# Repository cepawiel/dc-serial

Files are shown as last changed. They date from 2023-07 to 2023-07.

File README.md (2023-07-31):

# Dreamcast Serial Adapters

## [CP2102N Adapter](DCSDv2_CP2102N/README.md)
Replacement PCB for the Dreamcast SD to Serial adapters
that are available online. Intended to be used with [dcload-serial](https://github.com/KallistiOS/dcload-serial/) for development of homebrew.
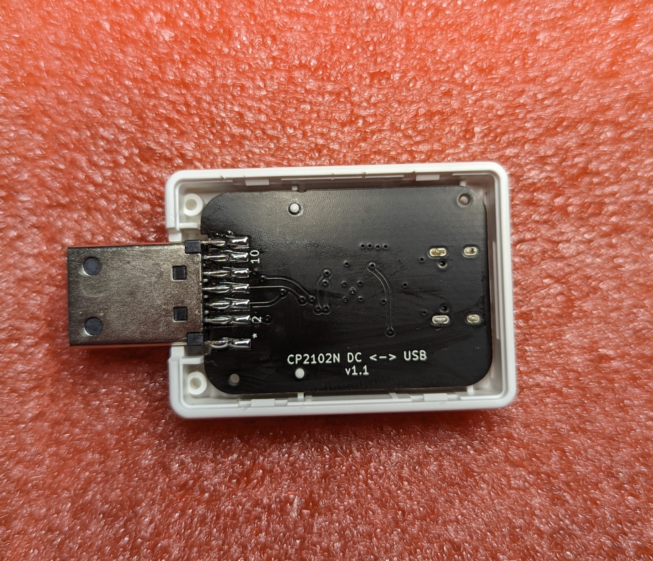
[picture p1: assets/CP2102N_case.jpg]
PCB in DCSDv2 Case

Upload while connected to DC

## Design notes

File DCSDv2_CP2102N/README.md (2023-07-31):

# CP2102N Adapter

## Info
This is a serial adapter designed around the CP2102N USB <-> Serial IC. 

On the PCB there's solder jumpers for connecting the clock and serial pins. I haven't experimented with using them yet, but that was the intention behind including them.

## Programing
By default the LEDs are not enabled, but can be using the [USBXpress]() software from Silicon Labs. Various other options include setting the Manufacturer & Product Strings. A [brief guide](https://www.silabs.com/documents/public/application-notes/AN721.pdf) to the tool is avaiable. To enable the LEDs make sure the "Alternate Function" for GPIO0 & 1 are set to the TX & RX Toggle options.
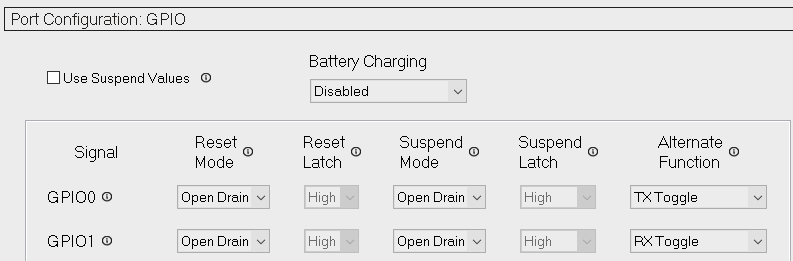
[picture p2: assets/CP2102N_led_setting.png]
GPIO Config Options


## Ordering
Files for ordering from JLCPCB are avaiable [here](jlcpcb/production_files/) including assembly files. I do usually select the option for them to double check the pick and place file since I believe I'm doing something incorrect with respect to the origin. In addition to the PCBs and components you'll need to procure a Dreamcast SD Adapter that are avaiable on Aliexpress/Ebay/Amazon ($10-$20) for the serial connector.

## Photos
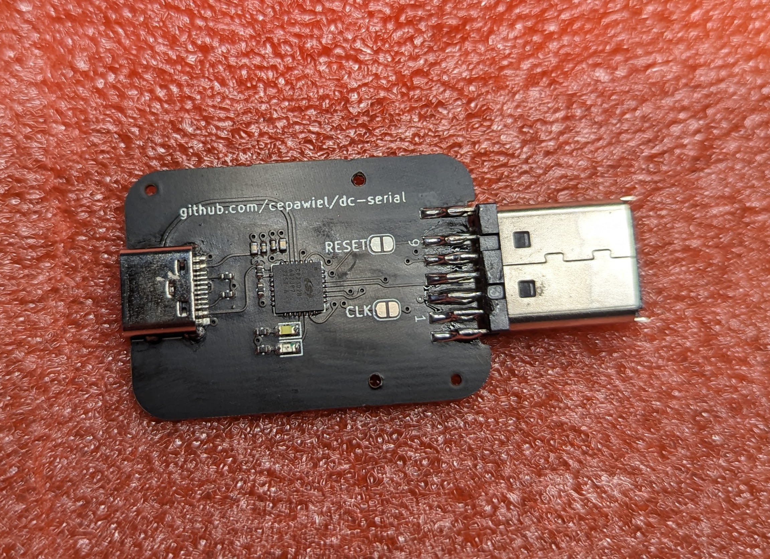
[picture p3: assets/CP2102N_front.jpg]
Front

Back
Case
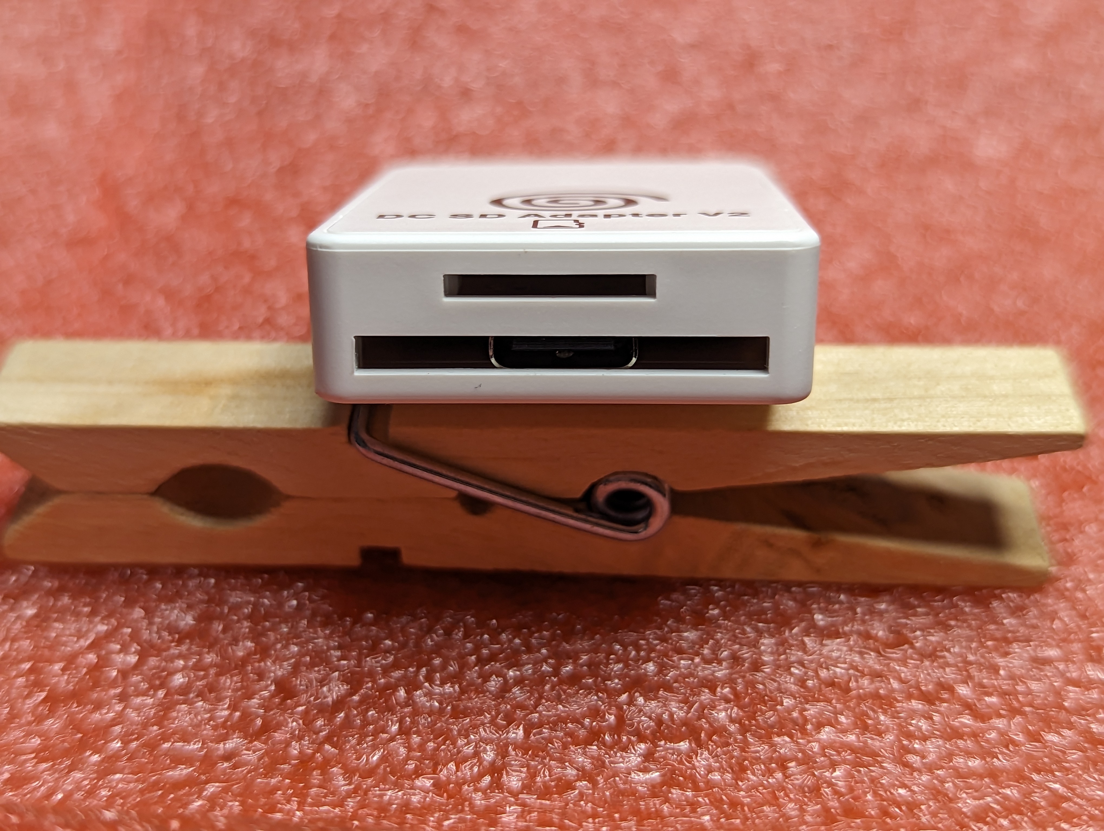
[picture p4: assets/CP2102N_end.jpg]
End

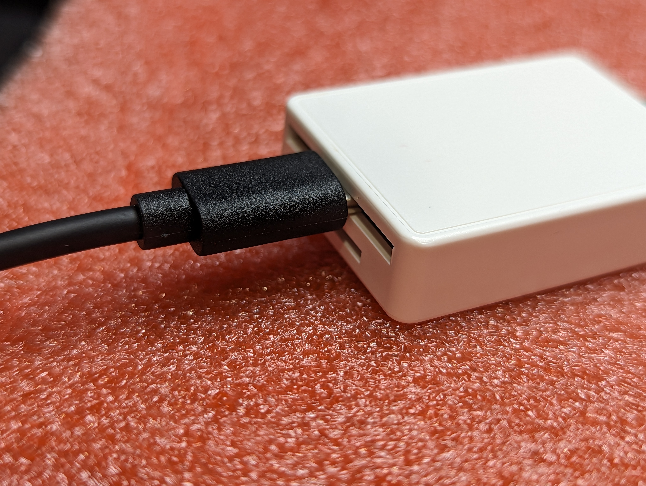
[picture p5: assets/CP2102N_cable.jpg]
USB Cable

Uploading GIF

## Changelog

### TODO
- Current PCB alignment holes are slightly too small. Using a 3/64" bit to widen holes allows for a pretty good fit.

### V1.1
- Swapped RX/TX & RTS/CTS
- Placed components on bottom to allow USB-C to fit without modifications to case

### V1.0
- Initial Order

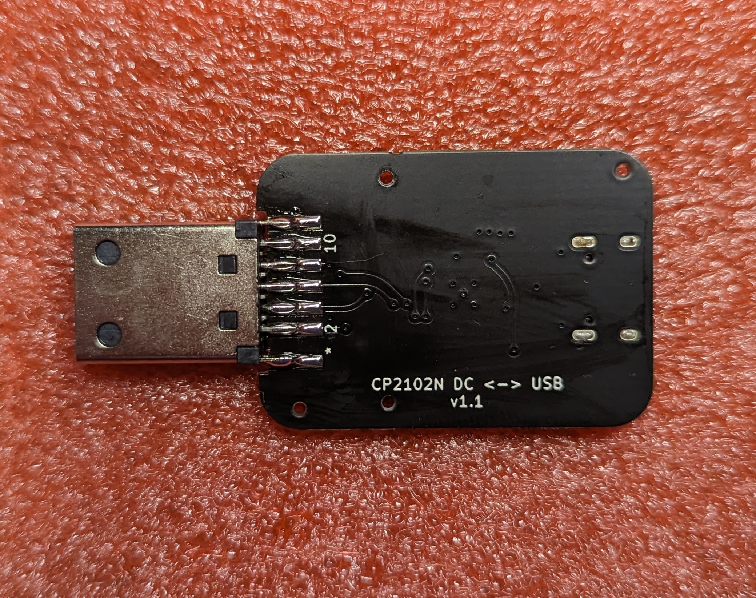
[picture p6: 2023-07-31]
assets/CP2102N_back.jpg

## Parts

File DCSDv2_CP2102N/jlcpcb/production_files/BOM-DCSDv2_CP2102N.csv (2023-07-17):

Comment | Designator | Footprint | LCSC
0.1uF | C1,C3 | C_0402_1005Metric | C1525
10uF | C2,C4 | C_0402_1005Metric | C15525
USB_C_Plug_USB2.0 | P1 | USB_C_Receptacle_HRO_TYPE-C-31-M-12 | C165948
LED | D1 | LED_0603_1608Metric | C2286
LED | D2 | LED_0603_1608Metric | C2290
R | R5,R6 | R_0402_1005Metric | C25133
22.1k | R3 | R_0402_1005Metric | C25765
47.5 | R4 | R_0402_1005Metric | C25792
5.1k | R1,R2 | R_0402_1005Metric | C25905
CP2102N-Axx-xQFN28 | U1 | QFN-28-1EP_5x5mm_P0.5mm_EP3.35x3.35mm | C964632
~ | U2 | DCSD_Serial

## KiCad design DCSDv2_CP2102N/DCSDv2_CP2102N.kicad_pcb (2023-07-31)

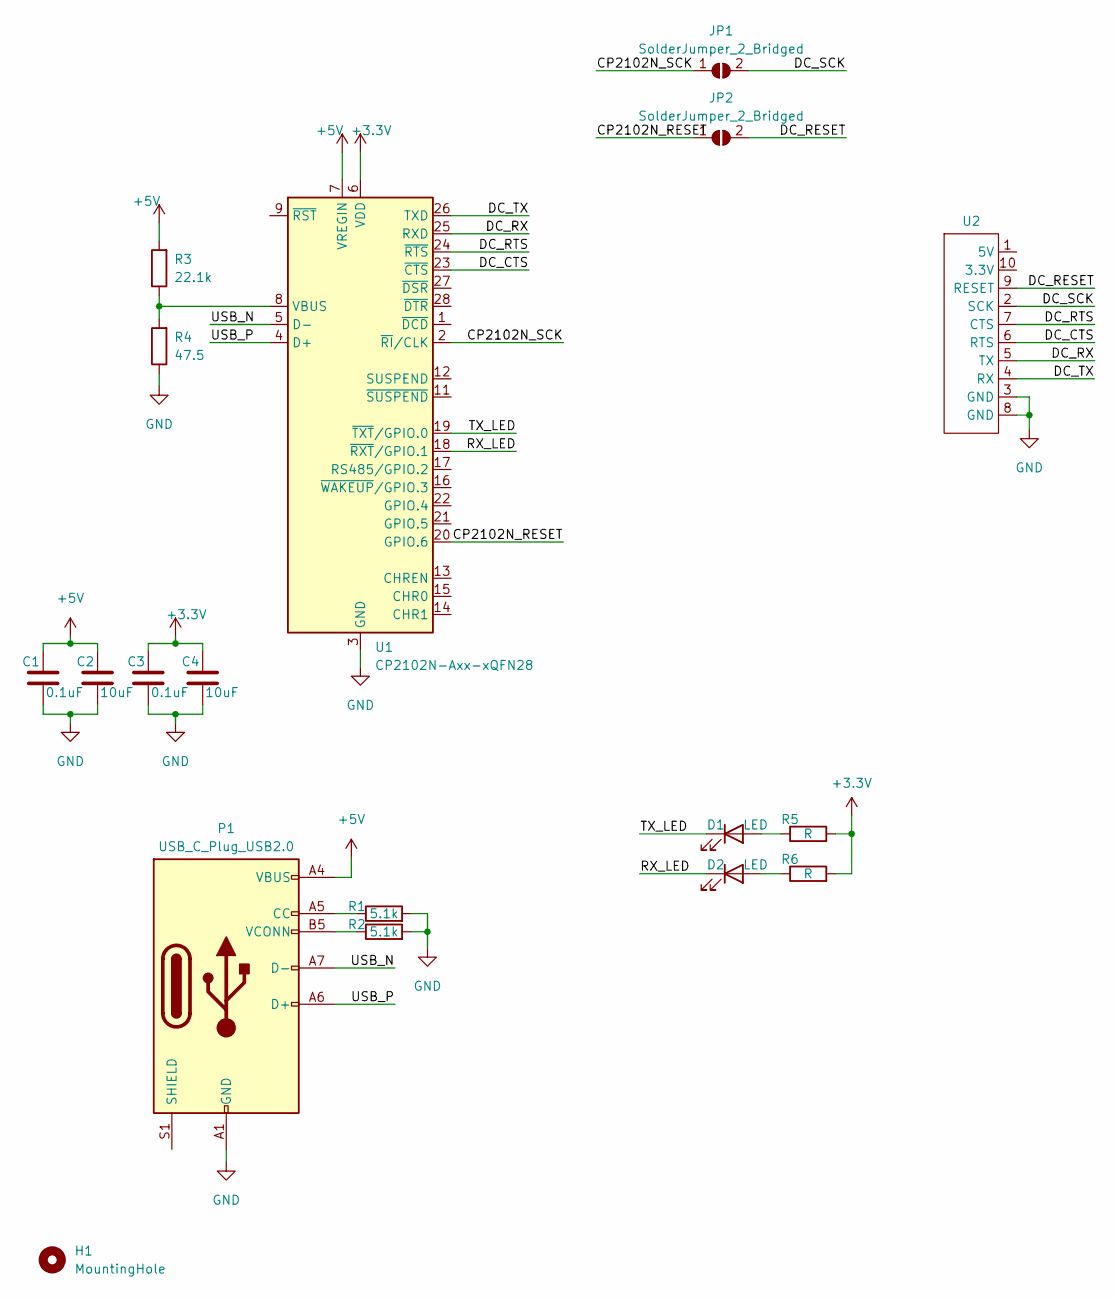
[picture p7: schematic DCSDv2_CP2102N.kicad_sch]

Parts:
C1, C3: 0.1uF; C_0402_1005Metric
C2, C4: 10uF; C_0402_1005Metric
D1, D2: LED; LED_0603_1608Metric
H1: MountingHole; DCSDv2
JP1, JP2: SolderJumper_2_Bridged; SolderJumper-2_P1.3mm_Open_RoundedPad1.0x1.5mm
P1: USB_C_Plug_USB2.0; USB_C_Receptacle_HRO_TYPE-C-31-M-12
R1, R2: 5.1k; R_0402_1005Metric
R3: 22.1k; R_0402_1005Metric
R4: 47.5; R_0402_1005Metric
R5, R6: R; R_0402_1005Metric
U1: CP2102N-Axx-xQFN28; QFN-28-1EP_5x5mm_P0.5mm_EP3.35x3.35mm
U2: DCSD_Serial

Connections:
+3.3V: C3.1, C4.1, R5.2, R6.2, U1.6 (VDD)
+5V: C1.1, C2.1, P1.A4 (VBUS), P1.A9 (VBUS), P1.B4 (VBUS), P1.B9 (VBUS), R3.2, U1.7 (VREGIN)
/CP2102N_RESET: JP2.1 (A), U1.20 (GPIO.6)
/CP2102N_SCK: JP1.1 (A), U1.2 (~RI/CLK)
/DC_CTS: U1.23 (~CTS), U2.6 (RTS)
/DC_RESET: JP2.2 (B), U2.9 (RESET)
/DC_RTS: U1.24 (~RTS), U2.7 (CTS)
/DC_RX: U1.25 (RXD), U2.5 (TX)
/DC_SCK: JP1.2 (B), U2.2 (SCK)
/DC_TX: U1.26 (TXD), U2.4 (RX)
/RX_LED: D2.1 (K), U1.18 (~RXT/GPIO.1)
/TX_LED: D1.1 (K), U1.19 (~TXT/GPIO.0)
/USB_N: P1.A7 (D-), P1.B7 (D-), U1.5 (D-)
/USB_P: P1.A6 (D+), P1.B6 (D+), U1.4 (D+)
GND: C1.2, C2.2, C3.2, C4.2, P1.A1 (GND), P1.A12 (GND), P1.B1 (GND), P1.B12 (GND), R1.2, R2.2, R4.1, U1.3 (GND), U1.29 (GND), U2.3 (GND), U2.8 (GND)
unnamed: D1.2 (A), R5.1
unnamed: D2.2 (A), R6.1
unnamed: P1.A5 (CC), R1.1
unnamed: P1.B5 (VCONN), R2.1
unnamed: R3.1, R4.2, U1.8 (VBUS)

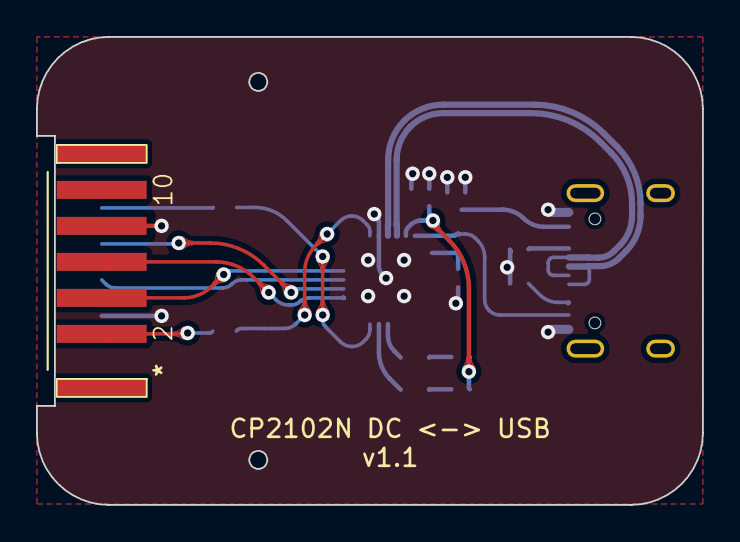
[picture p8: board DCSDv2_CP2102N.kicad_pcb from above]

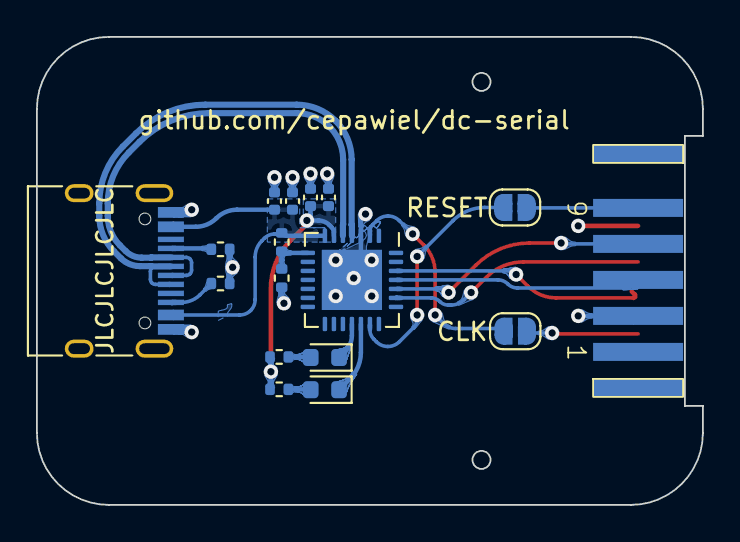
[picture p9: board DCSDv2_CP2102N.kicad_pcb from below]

Board: 2 copper layers, 37.0 x 26.0 mm, 18 parts (17 on the bottom side), 20 nets.

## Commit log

2023-07-17 First PCB Order
    [BOM-DCSDv2_CP2102N.csv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]
2023-07-31 Version 1.1
    [CPL-DCSDv2_CP2102N.csv, DCSDv2_CP2102N-CuBottom.gbr, DCSDv2_CP2102N-CuTop.gbr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]
